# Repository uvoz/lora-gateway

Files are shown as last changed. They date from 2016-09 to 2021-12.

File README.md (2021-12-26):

# lora indoor gateway housing

<b>Box designed by Adam Cigler - www.vjemy.cz</b> <br/>
<b>Hardware integration logic designed by Bob Heida</b> <br/><br/>

This is a design for a Lora gateway.  The housing can stand on a table ar hang on magnetic surfaces (such as a fridge or a car).
The housing is designed to integrate a Rasberry PI-3 and the European IMST iC880A LoRaWAN Concentrator board (868MHz) as electronics.

Pins of both boards are kept as near as possible to eliminate the need of long cables and hence reduces signal losses and interference.

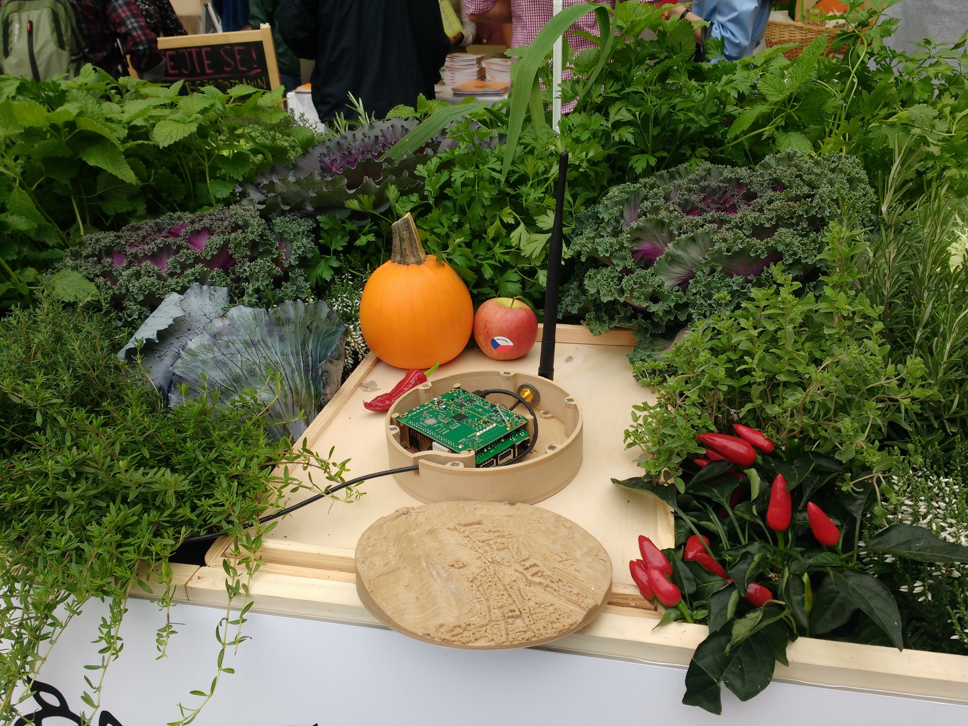
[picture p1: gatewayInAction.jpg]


<b>Mounting hardware</b> <br/>
The Raspberry can be fixed in the "electronics-integration-module" with M2 nuts and bolts(24mm length).

<b>Magnets</b> <br/>
Mounting the box and lid is done with 6 neodymium magents (4mm cubes).
The electronics are magneto-mounted into the box using a 12mm flat neodymium in the box and a 11mm washer ring.
On the botom of the box, 6 4mm neodymium cubes are mountable to be able to snap the gateway on a magnetic surface.
(or snap it on the inside of a window using other magnets on the outside..)

<b>Glue</b> <br/>
Magnets and the washer should be glued-in with epoxy.

<b>Tests</b> <br/>
We have tested this gateway for a month or two with The Things Network and found no influence of the magnets on the electronics. 

The short wiring helps providing a stable gateway without shielding the case. 

<br/><br/>
<b>Outdoor off-the-shelf boxes</b>
To accomodate outdoor installations in off-the-shelf waterproof DIN cases, the DIN interface file can be 3d-printed. This enables re-usage of the neat electronics-integration-module in such housing.
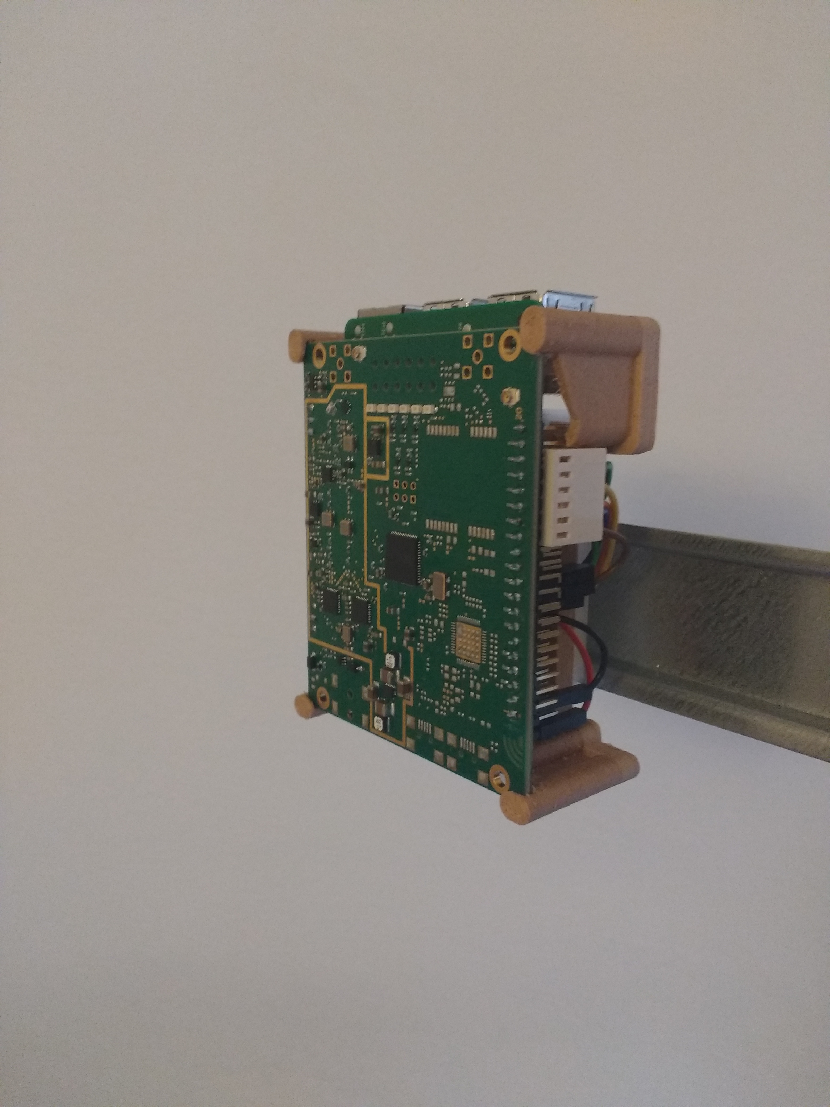
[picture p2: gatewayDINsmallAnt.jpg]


<H1>Wiring the boards and installing the gateway software</H1>
A description of how to wirie the electronics and the perform the installation procedure for this TTN compatible gateway can be found here:

[https://github.com/ttn-zh/ic880a-gateway](https://github.com/ttn-zh/ic880a-gateway)
<br/><br/>It's a one hour exercise..

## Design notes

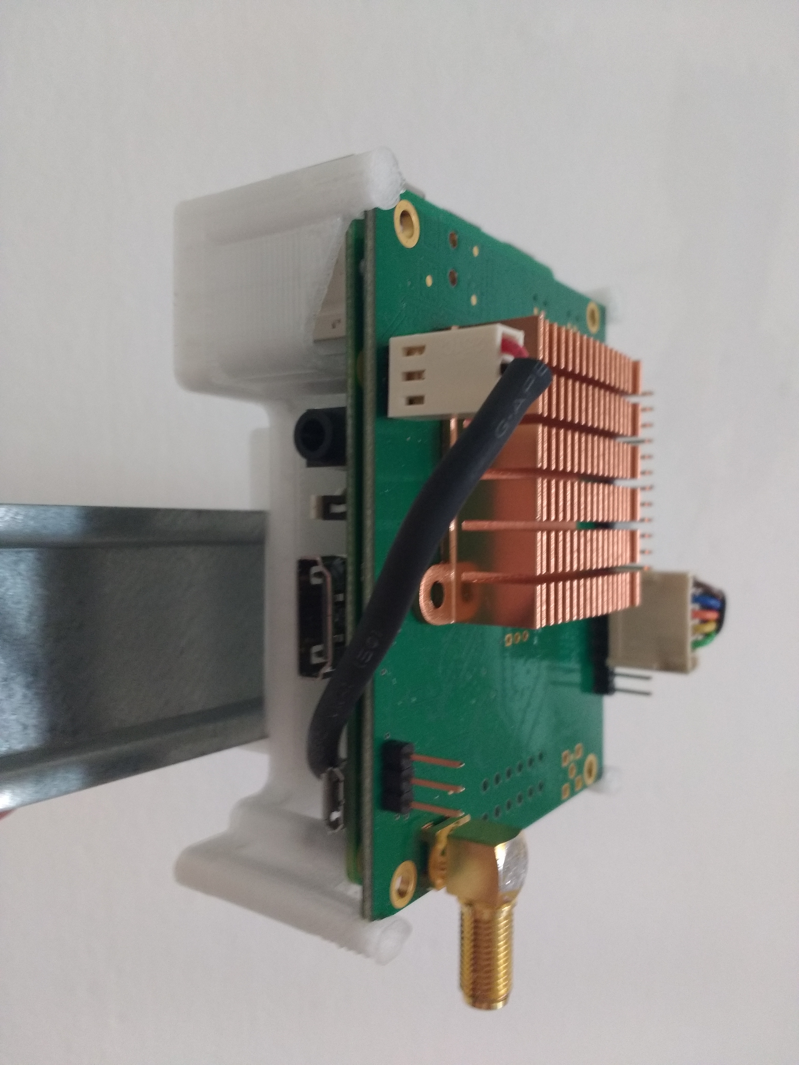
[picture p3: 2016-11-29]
gatewayDINbigAnt.jpg

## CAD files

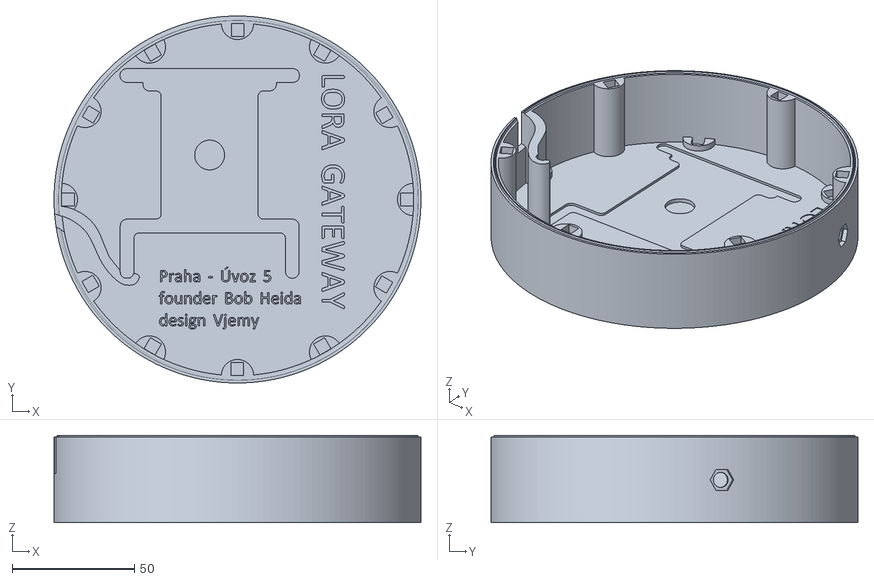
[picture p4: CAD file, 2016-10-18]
box.STL
150.0 x 150.0 x 35.7

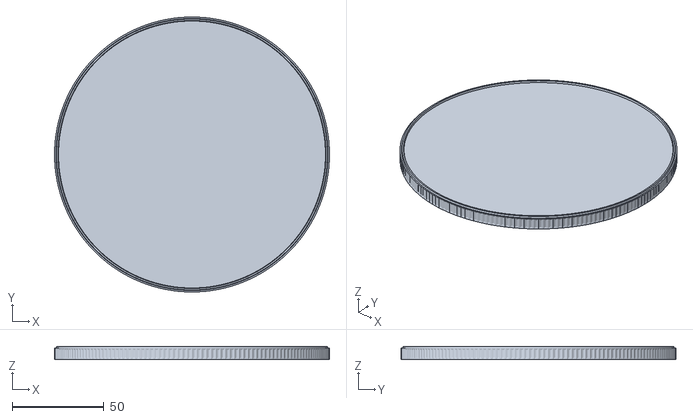
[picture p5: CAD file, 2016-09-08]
lid.STL
150.0 x 150.0 x 7.20

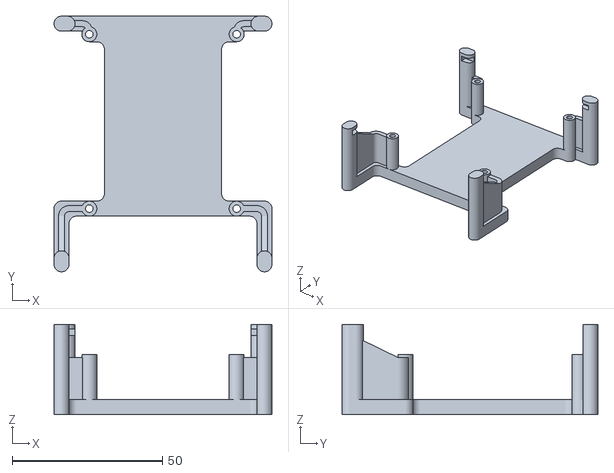
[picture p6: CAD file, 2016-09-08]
board-holder.STL
72.5 x 85.0 x 30.0

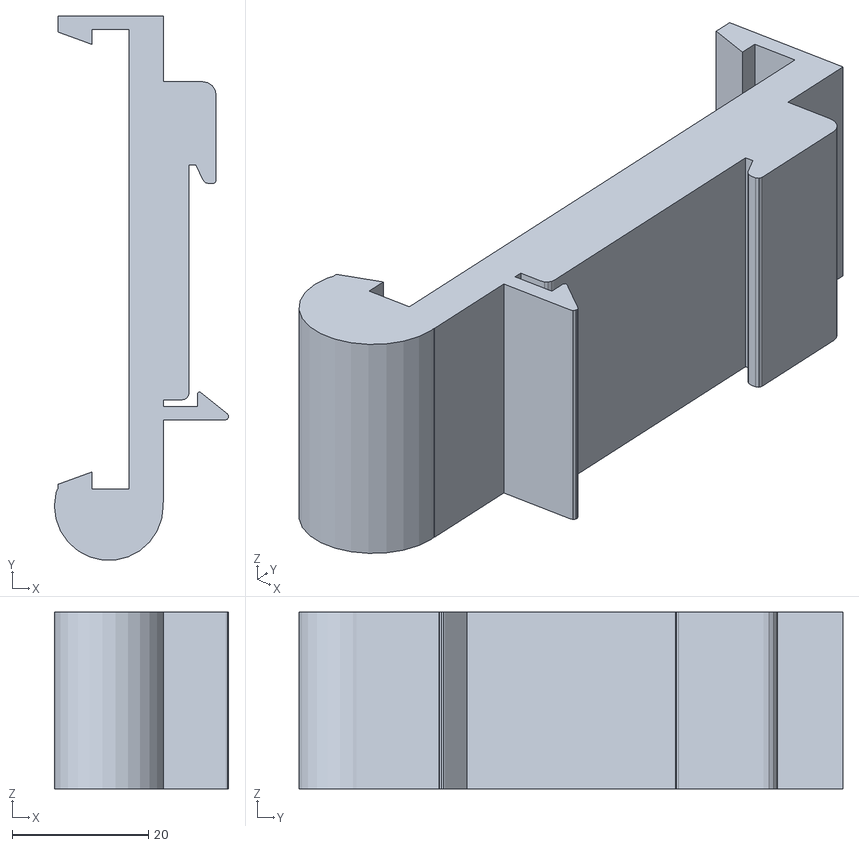
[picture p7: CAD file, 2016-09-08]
lorawan gateway din interface for Adam's holder.stl
25.6 x 79.9 x 26.0

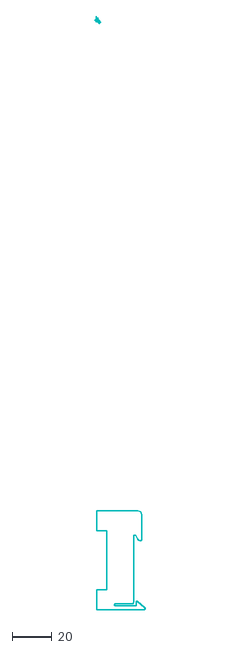
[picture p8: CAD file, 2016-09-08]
din_clip_02.dxf
25.4 x 298.3

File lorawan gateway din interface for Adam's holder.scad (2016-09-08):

CLIP_H = 26;


module din_clip() {
	
	difference() {

		linear_extrude(height=CLIP_H, center=true, convexity=5) {
			import(file="din_clip_02.dxf", layer="0", $fn=64);
		}
}
}

module interfacetoadapter()
{
//base plate
translate([10,-10,-CLIP_H/2])
cube([5,67.5,CLIP_H]);


//lower clip **********
//5mm up
translate([4.5,-12,-CLIP_H/2])
cube([10.5,2,CLIP_H]);

difference(){
//5mm up around corner
translate([-.5,-12,-CLIP_H/2])
cube([5,8,CLIP_H]);

//cut corner
translate([-6.5,-3,-CLIP_H/2])
rotate([0,0,-70])
cube([8,12,CLIP_H]);
}



//higher clip **********
//5mm up
translate([4.5,57.5,-CLIP_H/2])
cube([10.5,2,CLIP_H]);

difference(){
//5mm up around corner
translate([-.5,51.5,-CLIP_H/2])
cube([5,8,CLIP_H]);

//cut corner
translate([4,47,-CLIP_H/2])
rotate([0,0,70])
cube([8,20,CLIP_H]);

}


//extra hang support 
difference(){
translate([7,-12.5,-CLIP_H/2])
cylinder(h=CLIP_H, r1=8,r2=8);
translate([-5,-10,-CLIP_H/2])
cube([20,10,CLIP_H]);
}



}



difference(){
din_clip();
//base plate
translate([0,0,-CLIP_H/2])
cube([10,66.5,CLIP_H]);

}



interfacetoadapter();

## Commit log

2016-09-08 Added a DIN clip to be able to mount the inner structure on a DIN rail
    Made for a outdoor installation in Blatna that requires water-proof outdoor-box installation.
    Based on the DIN-pcb mount from RobertHunt.
    http://www.thingiverse.com/thing:101024
    [din_clip_02.dxf, lorawan gateway din interface for Adam's holder.scad, lorawan gateway din interface for Adam's holder.stl]
2016-09-08 STL files from Adam added
    Mesto021.rar is the lid
    decupeler01.stl is the box
    drzak chipu05.stl is the electronics integration module
    [decupeler01.STL, drzak chipu05.STL]
2016-10-17 code files are printer and material specific..
2016-10-18 stl files have now understandable names
    [board-holder.STL, box.STL, lid.STL]
